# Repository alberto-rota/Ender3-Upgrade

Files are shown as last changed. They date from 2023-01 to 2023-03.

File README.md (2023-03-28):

# Ender3-Upgrade
A collection of upgrades and mods I installed on my Creality Ender 3.

This repository includes:
- A CAD model of the 3D printer, that includes the modifications made to the original design
- Downloadable `stl` files for the 3D printed parts
- The Marlin 2.0 firmware installed
- The PCB design for the custom electronic boards
  
***

<p align="center"> 
<a href="https://minhaskamal.github.io/DownGit/#/home?url=https://github.com/alberto-rota/Ender3-Upgrade/Printables">
<picture>
  <source media="(prefers-color-scheme: dark)" srcset="readme/download_stls_light.png">
  downloadstls 
</picture>
</a> </p>
All parts have been printed in standard 1.75 PLA filament, with a 4mm nozzle. They can be printer on any 3D printer, from hobbyist to professional. Print settings change depending on the part and the printer, but as long as a good bed adhesion is achieved, all parts will come out fine. The only part that requires a bit of support material in some place is the "Back case".

***
## Overview
The full Ender3 printer complete with all the upgrades is depicted below:

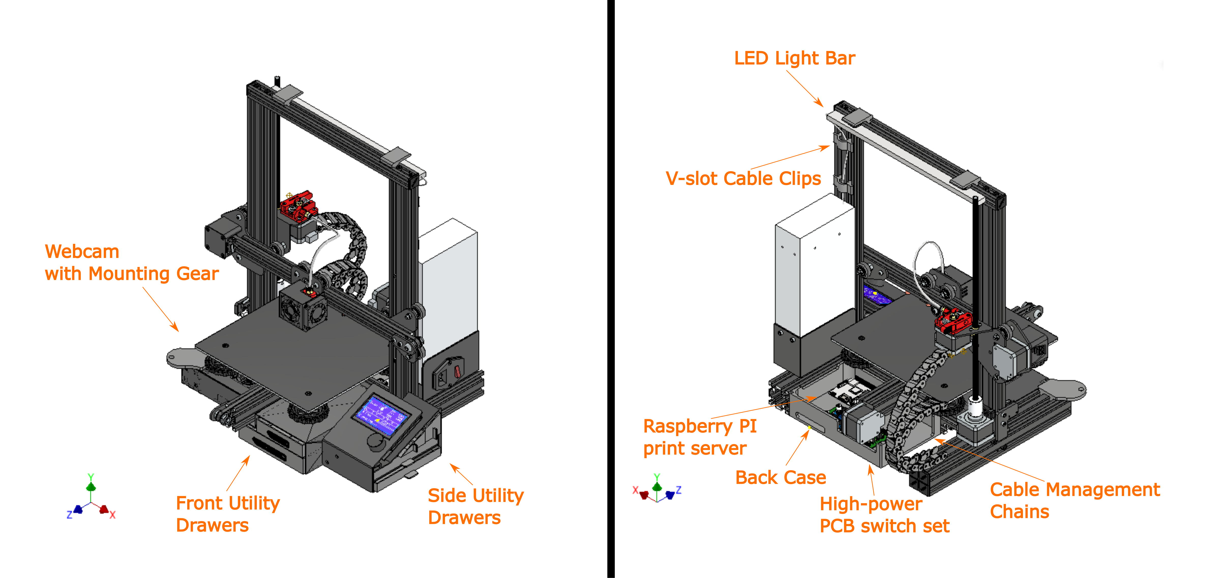
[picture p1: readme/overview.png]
overview

***
### Print Server
A Raspberry Pi 3A+ is used to host an OctoPrint server to remotely control and monitor the 3D printer. The Pi is powered from its separate power supply, connected to the printer via a USB cable, connected to the local network via WiFi (this was a limitation due to the available 3A+ model, a different model will be connected via Ethernet) and to an external USB webcam via a USB cable. A OTG USB hub (not in the picture) is necessary if using a 3A+

**NOTE:** This project was carried out during the COVID-19 pandemic, with the limited availability of electronics component (Pis cost more than 200€).

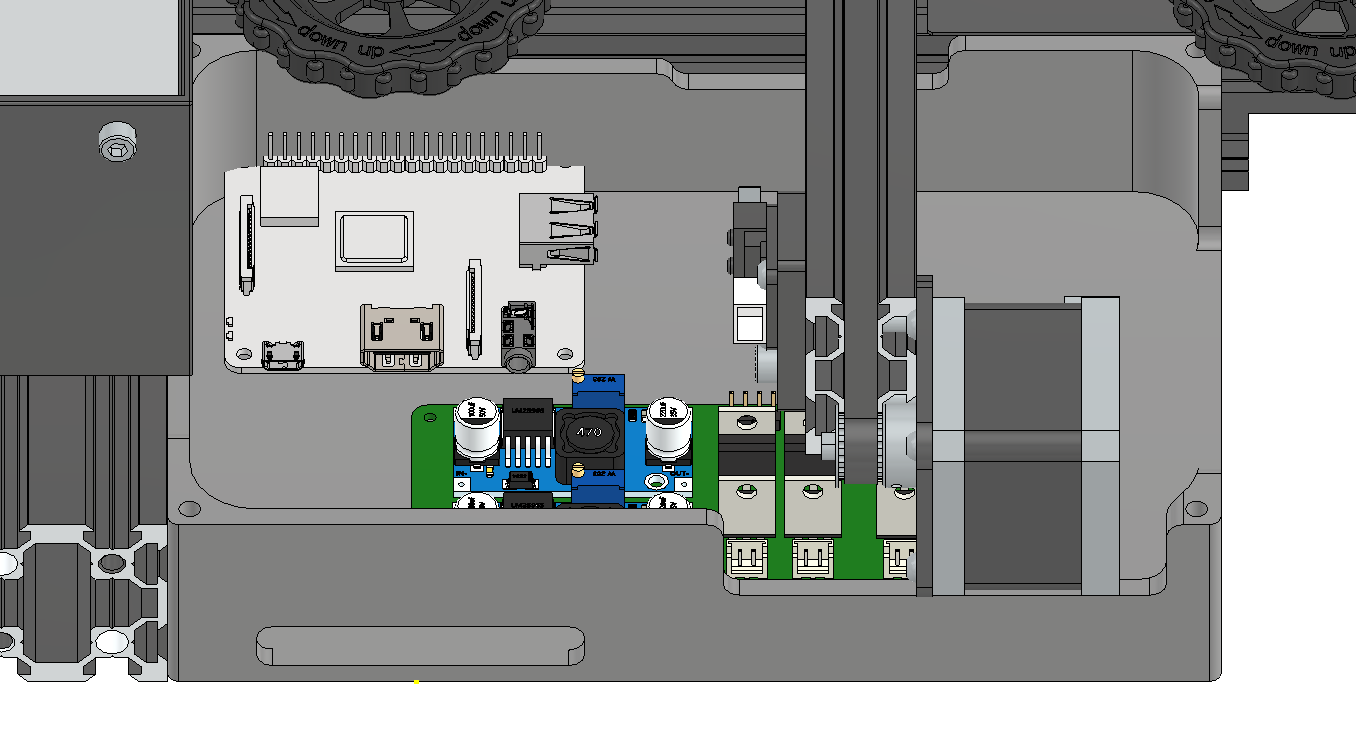
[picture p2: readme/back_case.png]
print server


In order to control "high-power" components from Octoprint (USB lights, custom Noctua Fans), a custom PCB mounting a set of MOSFET switches was custom designed and integrated in the printer. The PCB mounts 2 Buck converters to step down the 24V of the Power supply to 5V (for the USB lights) and 12V (for the Noctua fans) and is connected to the Raspberry via the GPIO pins.

The render and the schematics of the PCS are shown below:

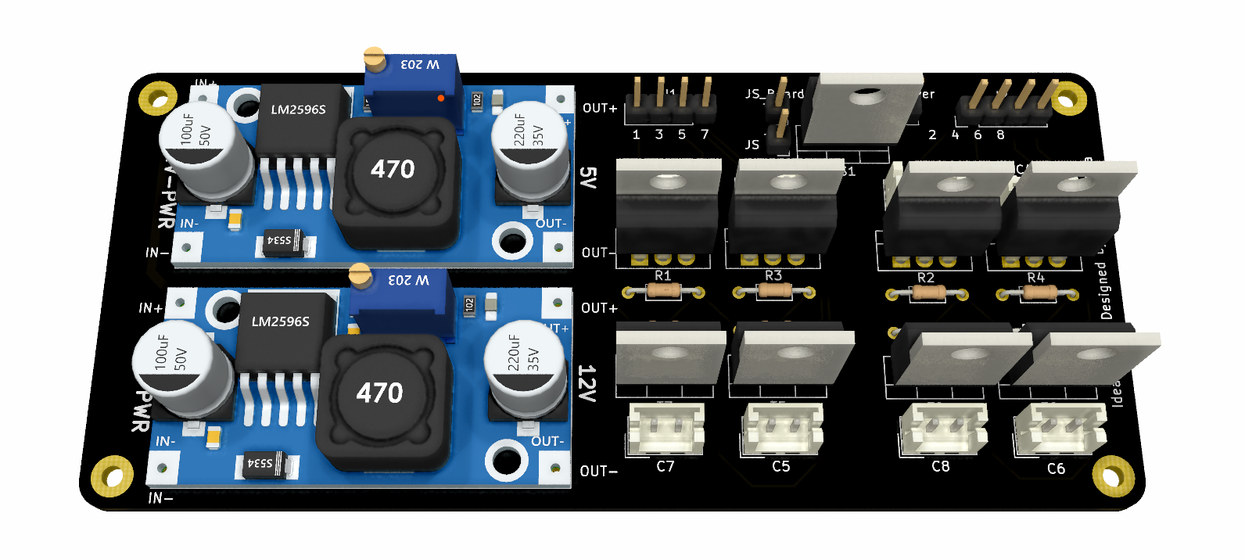
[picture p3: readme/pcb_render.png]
pcb render

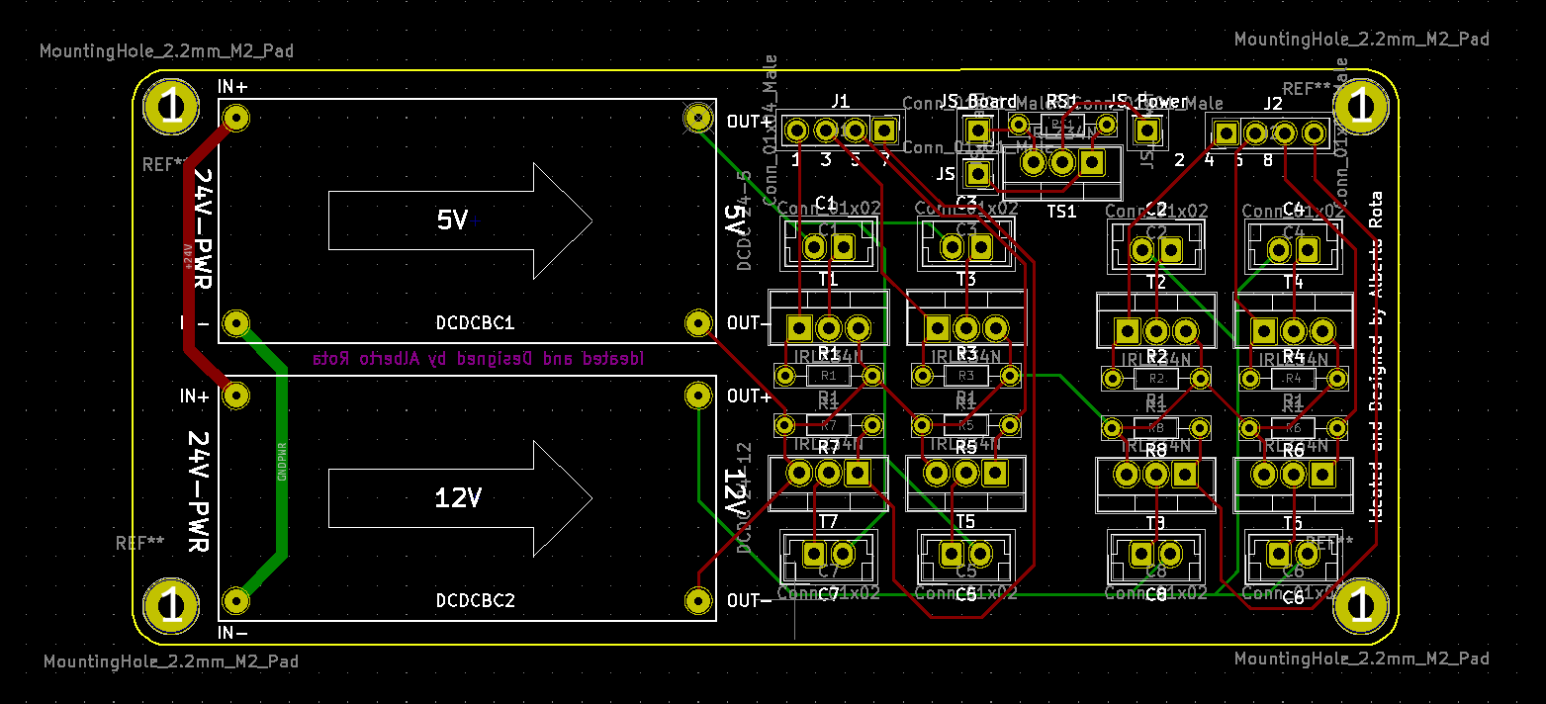
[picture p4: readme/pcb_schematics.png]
pcb schematics


The Pi, PCB, hub and cables are all positioned into a custom 3D printed case, that is mounted in the V-slots of the aluminum extruded profiles.

***
### USB light bar

A USB LED strip is mounted on the top horizontal frame of the printer, to provide a light source for the print bed. Two supports were necessary in order to hold the magnets that came with the LED bar and that hold it in place. The supports and custom clips that hold the cable in place are custom and designed for the V-slots.
The lights are controlled via Octoprint through the GPIO plugin.

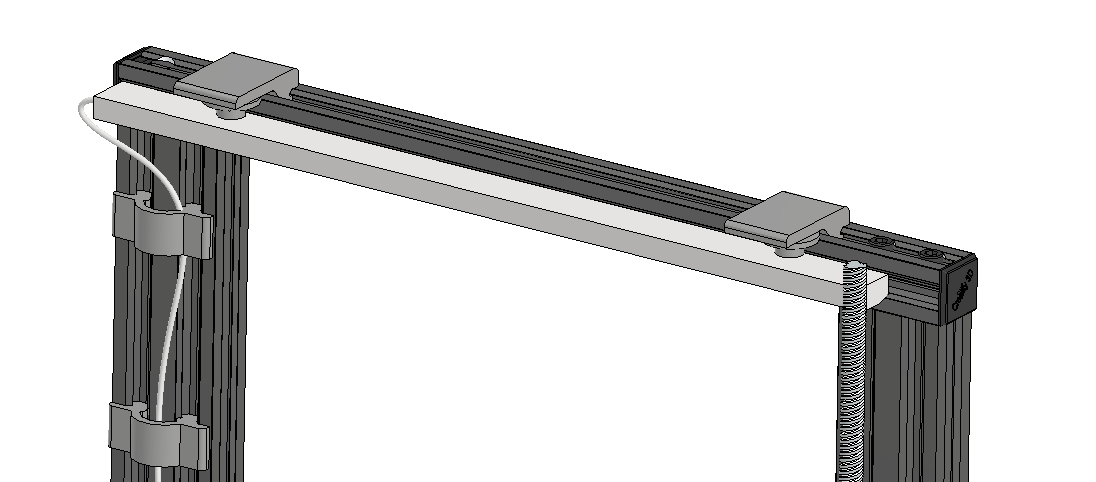
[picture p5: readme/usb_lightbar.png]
usb light bar


***
### Drawers
A set of 2 easy-access drawers have been positioned between the screen and the Y-Axis frame. The drawer container is, again, designed to fit in the V-slots of the aluminum extrusion.

Moreover, a set of 4 drawers has been placed behind the LCD screen of the printer. These drawers hold items which are more rarely accessed: nozzles, screws, springs, *etc.* The drwer container is held in place by the same screws that hold the LCD screen.

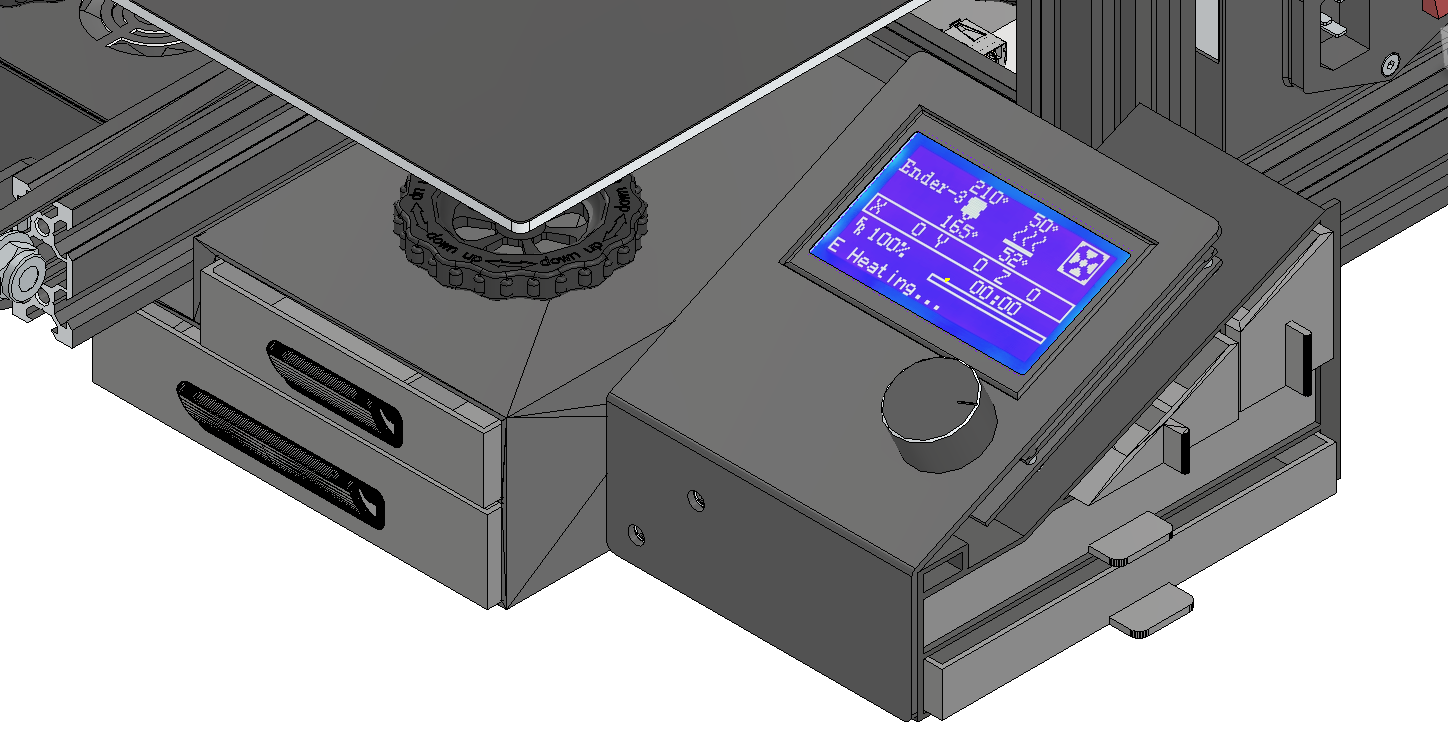
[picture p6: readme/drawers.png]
drawers

***
### Cable chain
A better cable management job was ensured with a set of cable covers that form a chain holding the cables tidy. One of this chain holds the cables that connect to the heated bed, the other holds the cables that connect to the extruder. The chain is mounted on the back of the printer, on the aluminum extrusion.

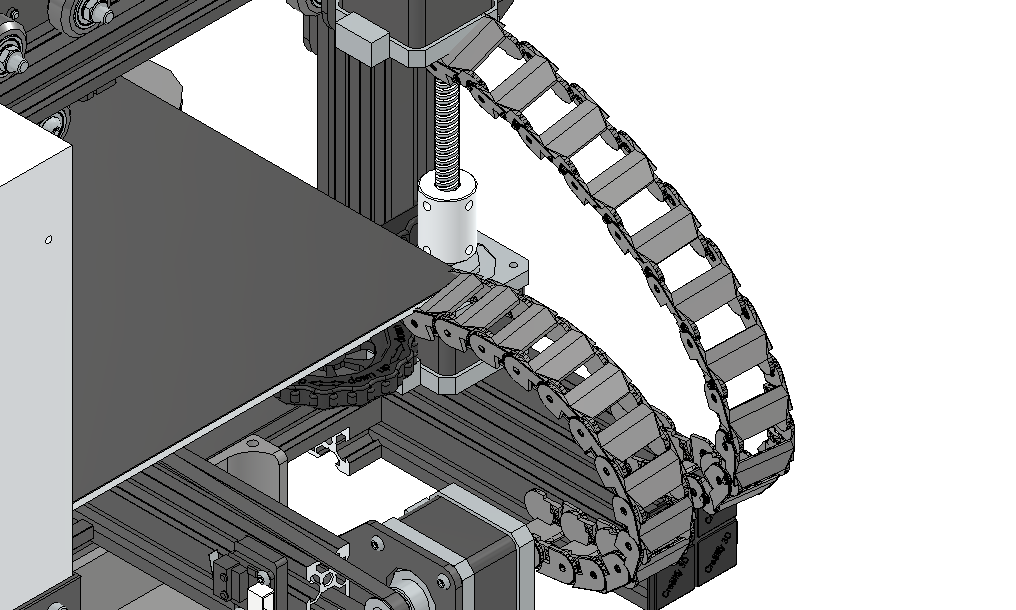
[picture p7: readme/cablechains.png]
cable chain

***
### Webcam Mount
A 3D printed mounting piece for a webcam. The shape and hole position are specific for the USB webcam I had at hand. The mount is designed to slide into the V-slots of the aluminum extruded profiles, with enough play to easily adjust its position along the extrusion.

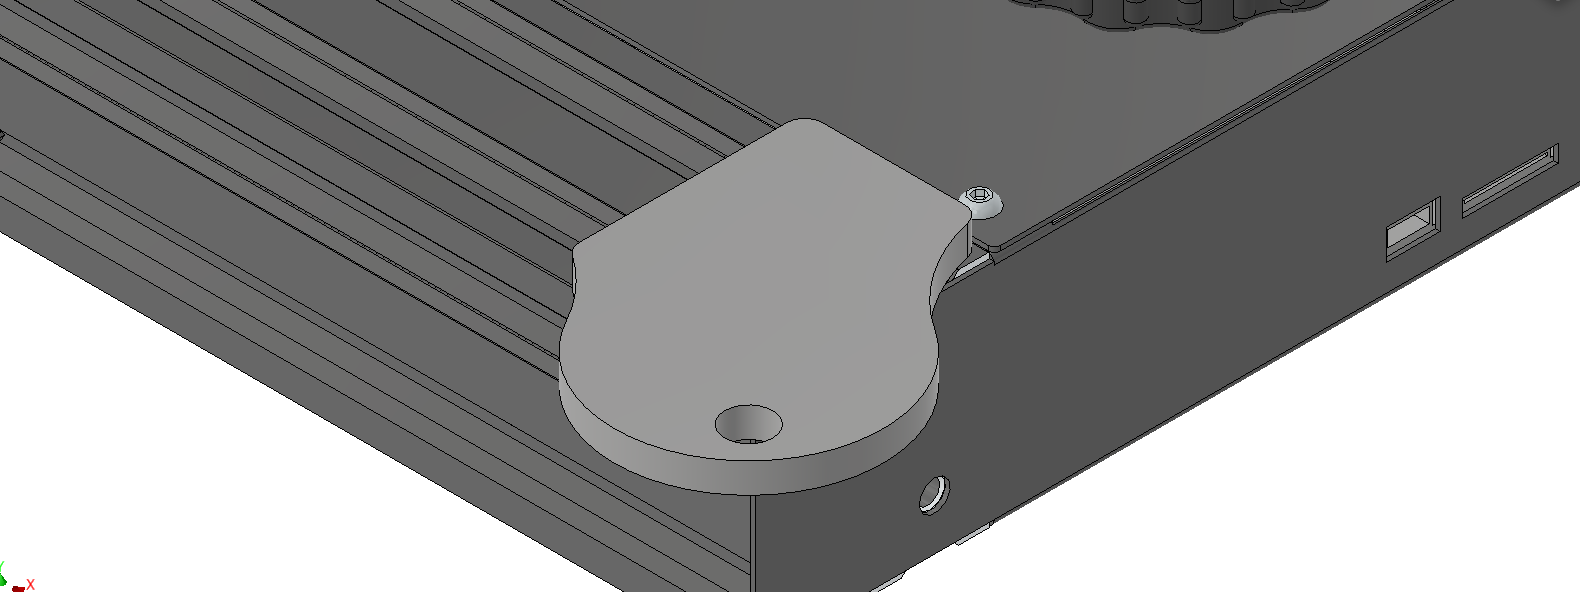
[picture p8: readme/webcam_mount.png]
webcam mount


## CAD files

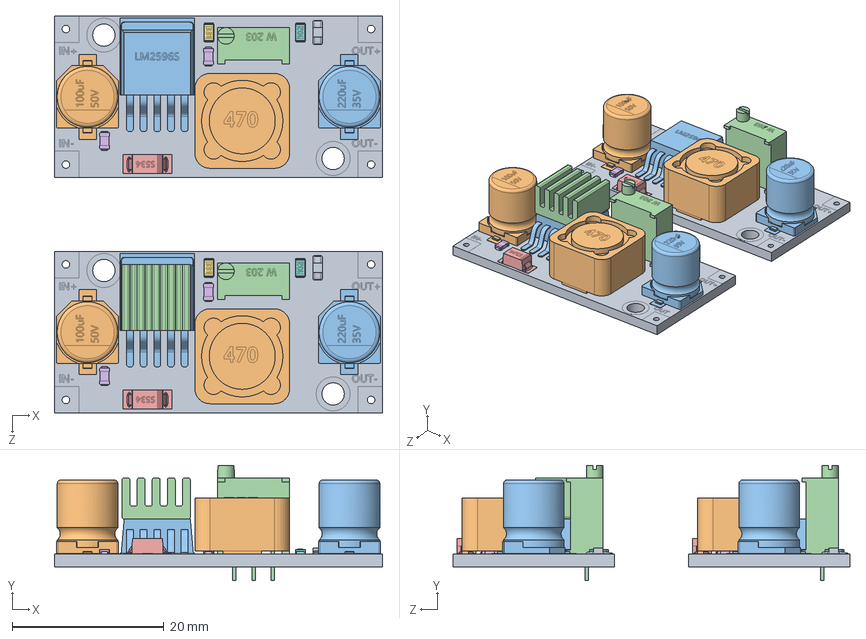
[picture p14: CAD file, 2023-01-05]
CAD/LM2596 DC to DC Buck Converter 3 A/LM2596 with and without cooler.SLDASM
43.2 x 15.1 x 52.3 mm
lm2596board x 2
smd100uF x 2
smd220uF x 2
TrimmerW203 x 2
smdS537diode x 2
smdceramiccapacitor x 4
smdResistor331 x 2
smdResistor102 x 2
smdLED x 2
smbInductor470 x 2
LM2596S x 2
IC Cooler

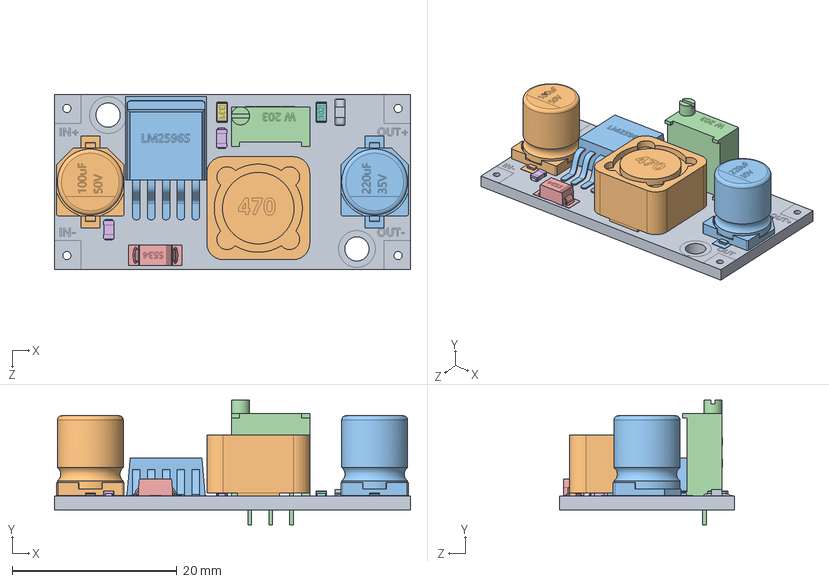
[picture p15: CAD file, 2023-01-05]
CAD/LM2596 DC to DC Buck Converter 3 A/converterLM2596.SLDASM
43.2 x 15.1 x 21.2 mm
lm2596board
smd100uF
smd220uF
TrimmerW203
smdS537diode
smdceramiccapacitor x 2
smdResistor331
smdResistor102
smdLED
smbInductor470
LM2596S

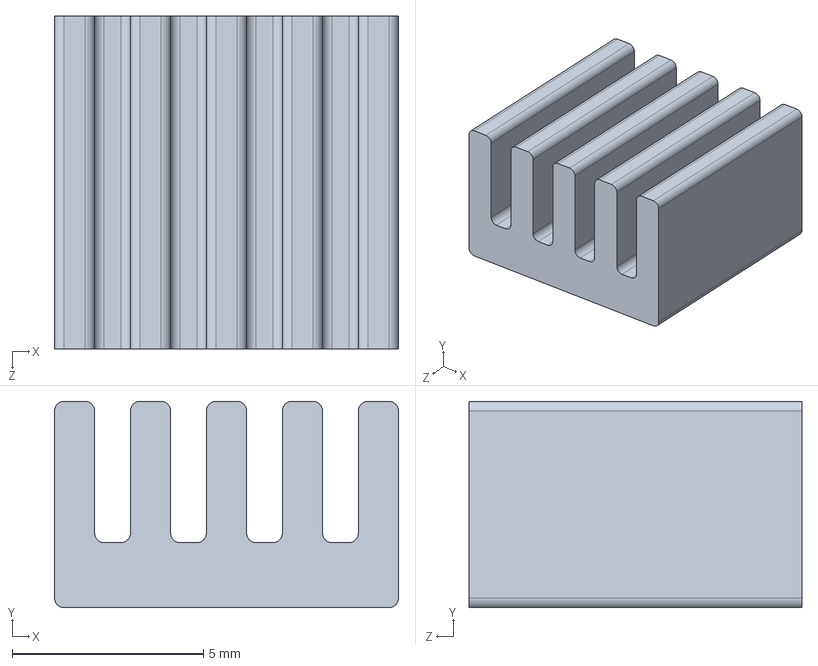
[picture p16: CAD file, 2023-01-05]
CAD/LM2596 DC to DC Buck Converter 3 A/IC Cooler.SLDPRT
9.00 x 5.40 x 8.70 mm

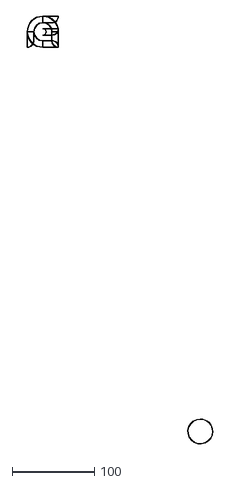
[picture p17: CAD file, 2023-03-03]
PCB/NEARLAB_LOGO.dxf
224.9 x 520.1

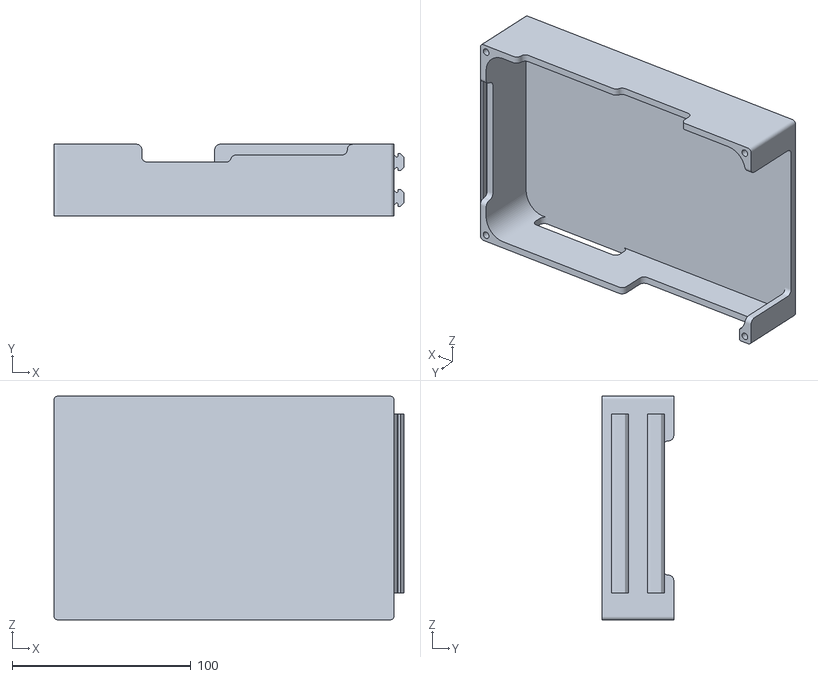
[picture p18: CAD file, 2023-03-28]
Printables/Back_Server_Case/Back_Case.stl
195.6 x 40.0 x 125.0

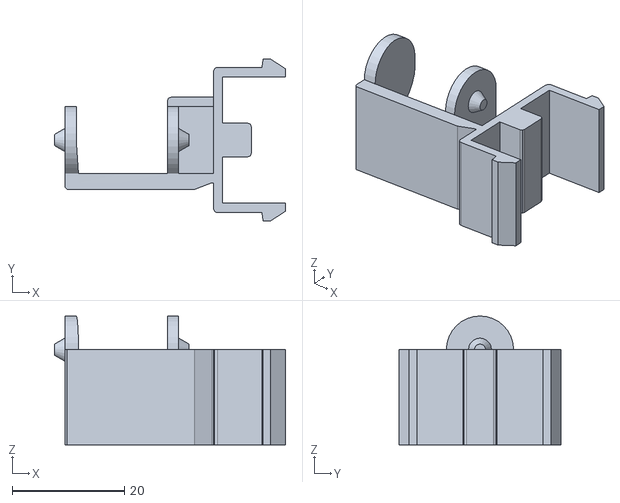
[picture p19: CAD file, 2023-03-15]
Printables/Cablechain/cableChain_40MountSide_v2.stl
41.2 x 28.9 x 23.0

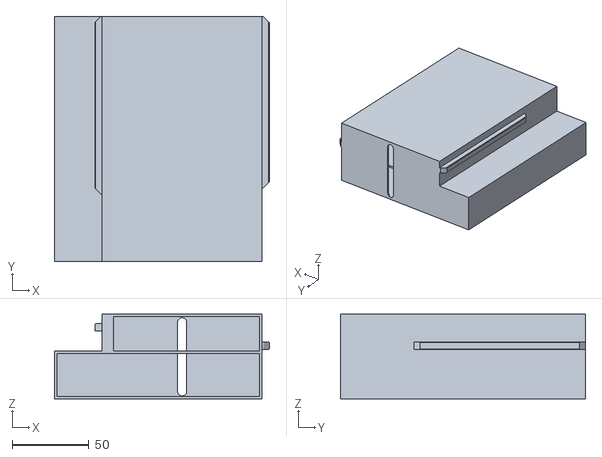
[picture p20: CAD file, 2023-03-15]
Printables/Front_Drawers/CASE.stl
140.3 x 160.0 x 55.4

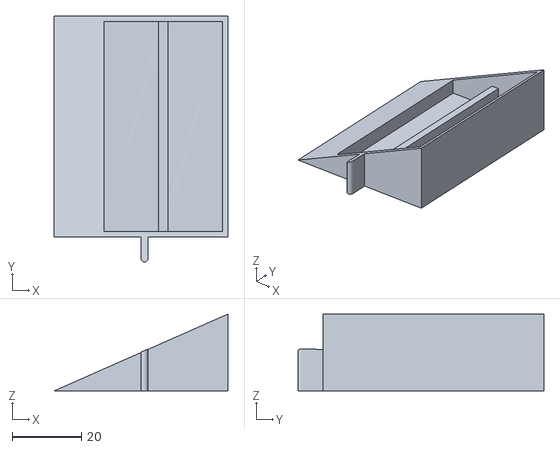
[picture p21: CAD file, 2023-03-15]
Printables/Side_Drawers/Drawer_TopLeft.stl
50.1 x 70.9 x 22.1

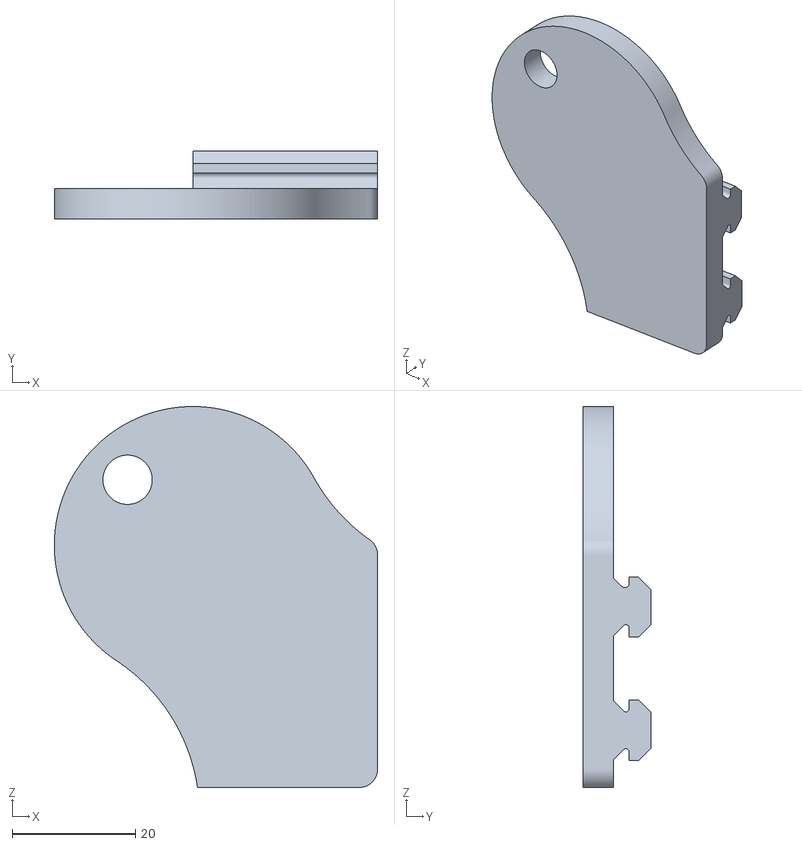
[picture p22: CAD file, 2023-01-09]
Printables/Webcam Mount.stl
52.5 x 11.1 x 61.9

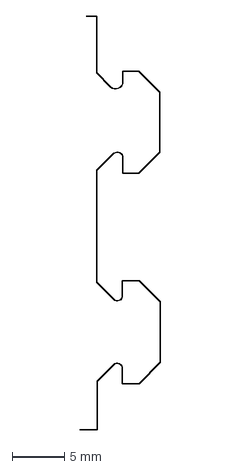
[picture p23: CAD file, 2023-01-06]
CAD/ExtrusionRail_40.dxf
7.67 x 39.4 mm

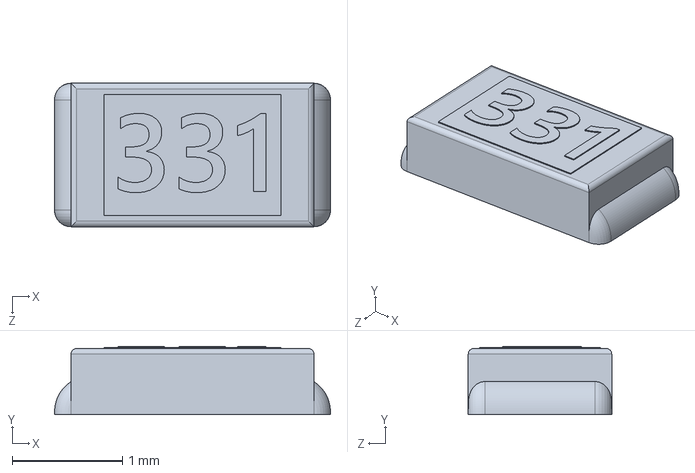
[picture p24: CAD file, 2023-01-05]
CAD/LM2596 DC to DC Buck Converter 3 A/smdResistor331.SLDPRT
2.50 x 0.62 x 1.30 mm

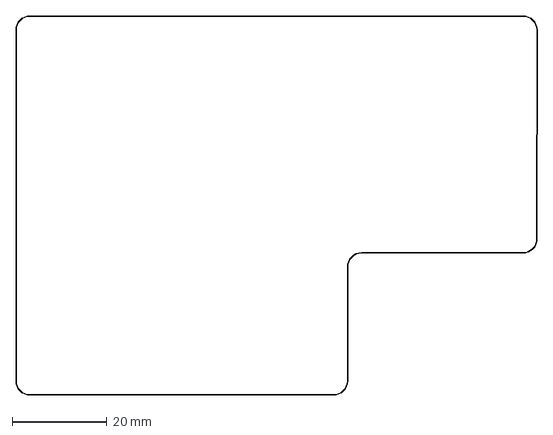
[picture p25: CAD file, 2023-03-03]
PCB/Outline.dxf
110.0 x 80.0 mm

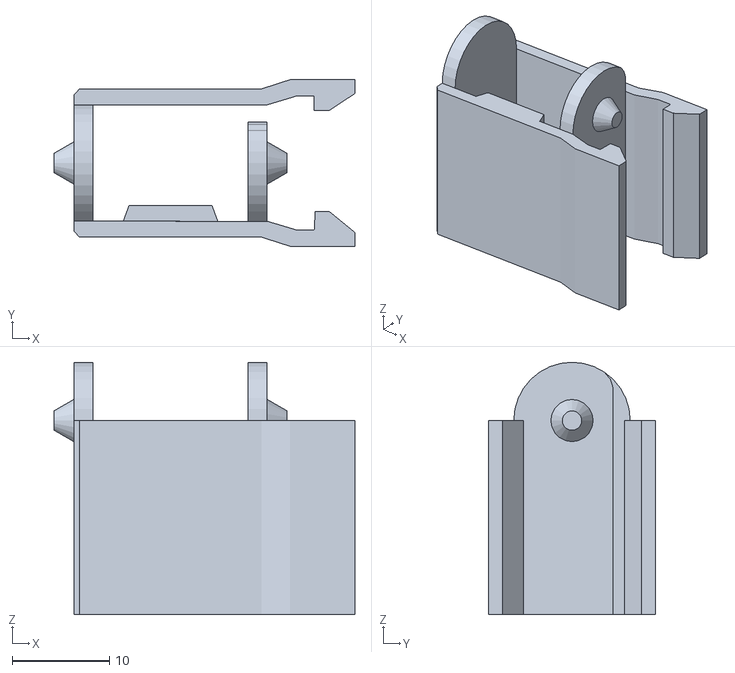
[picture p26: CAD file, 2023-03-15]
Printables/Cablechain/cableChain_40MountSide.stl
31.0 x 17.2 x 26.0

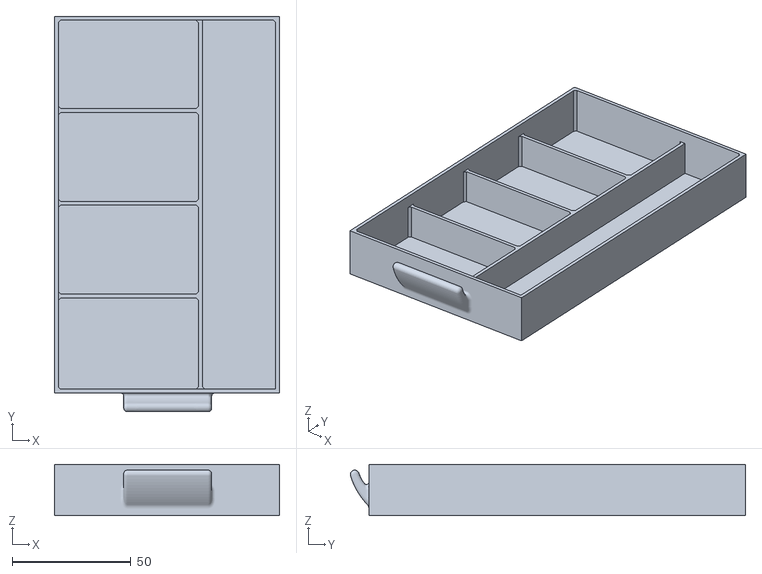
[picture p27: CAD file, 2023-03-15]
Printables/Front_Drawers/TOP_DRAWER.stl
94.6 x 166.3 x 21.6

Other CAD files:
CAD/CASE.stp
Printables/LED Bar Holder.stl
Printables/Side_Drawers/Drawer_Bottom.stl
CAD/ExtrusionRail_20.dxf
CAD/01 MAIN ASM Ender_3.iam
CAD/2020 Endcap.ipt
CAD/2020 profile.ipt
CAD/2020-2 profile.ipt
CAD/2040-2 profile.ipt
CAD/2040-3L profile.ipt
CAD/2040-3R profile.ipt
CAD/24V15A power supply.ipt
CAD/2GT-pulley.ipt
CAD/4040 profile.ipt
CAD/4040-3 profile.ipt
CAD/42-34 motor.ipt
CAD/624U pillow.ipt
CAD/625pillow.ipt
CAD/ASM Bed.iam
CAD/ASM Cable Chain.iam
CAD/ASM Display.iam
CAD/ASM Eccentrical Roller X-Axis.iam
CAD/ASM Eccentrical Roller Y-Axis.iam
CAD/ASM Eccentrical Roller Z-Axis Left.iam
CAD/ASM Eccentrical Roller Z-Axis Right.iam
CAD/ASM Electronic Enclosure.iam
CAD/ASM Extruder.iam
CAD/ASM Frame.iam
CAD/ASM Front Drawers.iam
CAD/ASM Front Drawers.ipt
CAD/ASM Heating Unit.iam
CAD/ASM PI Print Server.iam
CAD/ASM Power Supply.iam
CAD/ASM Printing Head.iam
CAD/ASM Roller Bolt.iam
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

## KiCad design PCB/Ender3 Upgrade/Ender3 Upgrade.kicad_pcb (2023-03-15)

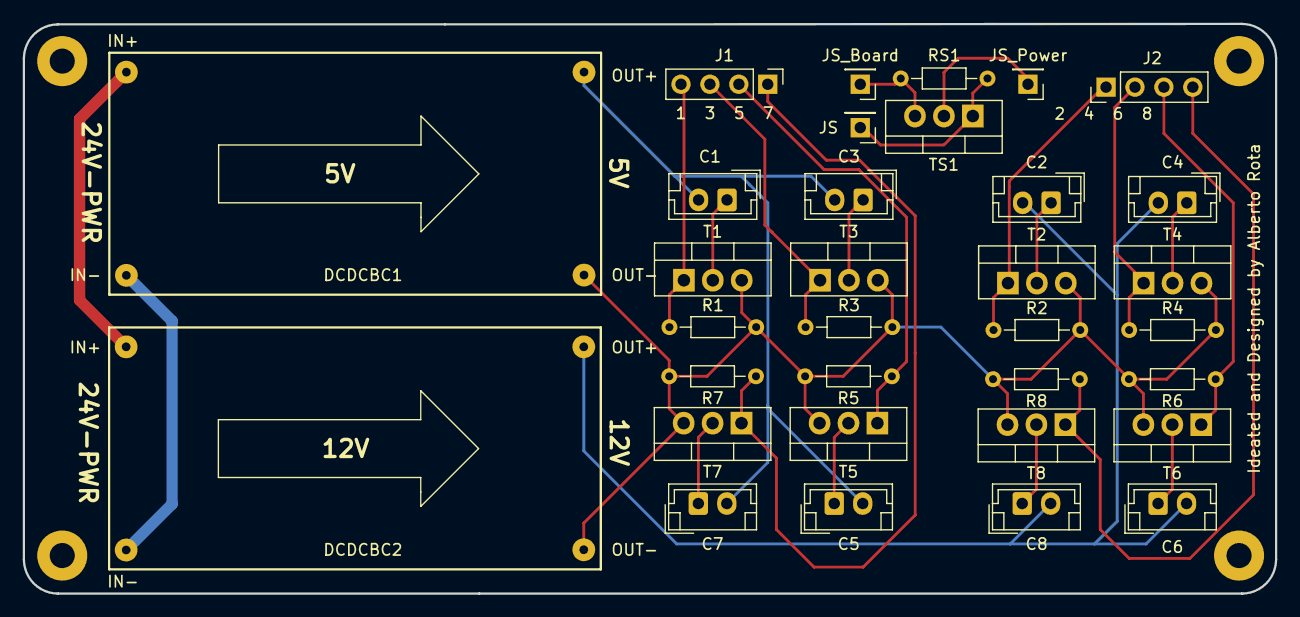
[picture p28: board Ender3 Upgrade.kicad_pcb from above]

Board: 2 copper layers, 110.0 x 50.0 mm, 33 parts (0 on the bottom side), 24 nets.

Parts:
C1, C2, C3, C4, C5, C6, C7, C8: Conn_01x02; JST_EH_B2B-EH-A_1x02_P2.50mm_Vertical
DCDCBC1: DCDC 24-5; BuckConverter
DCDCBC2: DCDC 24-12; BuckConverter
J1, J2: Conn_01x04_Male; PinHeader_1x04_P2.54mm_Vertical
JS: Conn_01x01_Male; PinHeader_1x01_P2.54mm_Vertical
JS_Board: Conn_01x01_Male; PinHeader_1x01_P2.54mm_Vertical
JS_Power: Conn_01x01_Male; PinHeader_1x01_P2.54mm_Vertical
R1, R2, R3, R4, R5, R6, R7, R8: R1; R_Axial_DIN0204_L3.6mm_D1.6mm_P7.62mm_Horizontal
RS1: R1; R_Axial_DIN0204_L3.6mm_D1.6mm_P7.62mm_Horizontal
T1, T2, T3, T4, T5, T6, T7, T8: IRLZ34N; TO-220-3_Vertical
TS1: IRLZ34N; TO-220-3_Vertical

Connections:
5V: C1.2, C3.2, C5.2, C7.2, DCDCBC1.4
12V: C2.2, C4.2, C6.2, C8.2, DCDCBC2.4
+24V: DCDCBC1.2, DCDCBC2.2
GND: DCDCBC1.3, DCDCBC2.3, R1.2, R2.2, R3.2, R4.2, R5.2, R6.2, R7.2, R8.2, T1.3, T2.3, T3.3, T4.3, T5.3, T6.3, T7.3, T8.3
GNDPWR: DCDCBC1.1, DCDCBC2.1
unnamed: C1.1, T1.2
unnamed: C2.1, T2.2
unnamed: C3.1, T3.2
unnamed: C4.1, T4.2
unnamed: C5.1, T5.2
unnamed: C6.1, T6.2
unnamed: C7.1, T7.2
unnamed: C8.1, T8.2
unnamed: J1.1, R7.1, T7.1
unnamed: J1.2, R5.1, T5.1
unnamed: J1.3, R3.1, T3.1
unnamed: J1.4, R1.1, T1.1
unnamed: J2.1, R2.1, T2.1
unnamed: J2.2, R4.1, T4.1
unnamed: J2.3, R6.1, T6.1
unnamed: J2.4, R8.1, T8.1
unnamed: JS_Board.1, RS1.2, TS1.3
unnamed: JS.1, RS1.1, TS1.1
unnamed: JS_Power.1, TS1.2

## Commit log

2023-01-05 Initial update
    [01 MAIN ASM Ender_3.0012.iam, 2020 Endcap.SLDDRW, 2020 Endcap.SLDPRT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]
2023-01-06 LED Wire Clip
    [01 MAIN ASM Ender_3.0012.iam, 2020 Endcap.SLDDRW, 2020 Endcap.SLDPRT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]
2023-01-07 Fixes Conflicting Relationships
    [ASM Frame.0004.iam, ASM Frame.0005.iam, ASM Frame.iam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]
2023-01-09 Camera mount
    [01 MAIN ASM Ender_3.0018.iam, 01 MAIN ASM Ender_3.iam, ASM Frame.0005.iam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]
2023-03-03 PCB Designed
    [01 MAIN ASM Ender_3.0018.iam, 01 MAIN ASM Ender_3.0020.iam, Back_Case.0001.ipt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]
2023-03-15 Drawers added
    [01 MAIN ASM Ender_3.0020.iam, ASM Eccentrical Roller Z-Axis Right.0001.iam, ASM Eccentrical Roller Z-Axis Right.iam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]
2023-03-15 Polished 3D models + Cool images
    [ASM Extruder.0001.iam, ASM Extruder.0002.iam, ASM Extruder.iam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]
